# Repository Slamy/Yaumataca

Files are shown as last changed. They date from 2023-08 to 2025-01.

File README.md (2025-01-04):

# Yet another USB mouse and joystick to Amiga, Atari ST &amp; C64 Adapter

Or in short Yaumataca. This device allows to use modern USB input devices
on 80s style home computer controller ports. Being mechanical in nature, old gamepads and mouses
degrade over time and replacements using modern variants might be required.

This solution makes use of the Raspberry Pi Pico board (RP2040) which offers a dedicated USB host controller
and can be bought at a rather low price (5-8€ per unit).
Cheap NPN transistors are used for level shifting as the RP2040 is not 5V tolerant.

## How to use

The Yaumataca acts as both Joystick and Mouse. Plug both output ports into both controller ports of the target machine.
Plug a USB OTG Hub into the Micro-USB port of the Pico board. Insert USB gamepad and USB mouse.

As multiple modes are supported, the [user manual](doc/user_manual.md) provides more detail.

## Features
* Cheap to build
* Uses "off the shelf" hardware
* Multiple USB devices on 2 Atari type controller ports using a single unit
* Primary joystick on left port
* Primary mouse on right port
* Amiga mouse with wheel using [WheelBusMouse](http://aminet.net/package/util/mouse/WheelBusMouse) driver
* Commodore 1351 in proportional mode
* Atari ST mouse
* Automatic switch between mouses and joysticks
* Swap of controller ports (useful for C64 games)
* Supports 2 mouses and 2 joysticks (useful for Lemmings and Marble Madness)
* Supports secondary fire button (Amiga and C64 style)
* Auto fire
* Configured mouse type is saved in flash

## Restrictions
* Only dedicated Joysticks are supported.
	* PS3 DualShock
	* PS4 DualShock
	* Nintendo Switch Pro Controller
	* Xbox 360 Wireless Receiver (1 or 2 controllers with one receiver)
	* Xbox One Controller
	* Xbox Series S/X Controller
	* Mega World International - USB Game Controllers (07b5:0314)
	* DragonInc Hizue Gamepad (0079:0011)

## TODO
* Amiga Mode: Add support for newmouse or Micromys protocol
	* Avoids necessity for manipulation of the unrelated joystick port
* Add 3. Fire button for more gamepads
* HID Descriptor Parsing (generic USB joystick support, eventually)
* Bluetooth (eventually)
* Explain C1351 calibration using C64 tool

## How to construct

The project is constructable via perfboard or PCB.

[Manual for construction on a perfboard](doc/construction_perfboard.md)

For the PCB, please use the [KiCad files](schematic/yaumataca/).
If you order your parts from [Reichelt](https//reichelt.de), you may use the
attached [ordering lists](doc/reichelt.csv) which can be imported on the website.

In case the PCB is chosen, there is also a [3D model of a case](housing/) available, which can be used for 3D printing.

To operate the unit, one OTG Hub is recommended which provides multiple USB A ports attached to a USB micro port.
If only one USB device is to be attached, a simple USB micro to USB A adapter will also work, but I suggest to go for the Hub.

### Example hardware design

Here an example of the PCB inside the case.
Photo of Yaumataca in 3d printed case

Here the PCB side by side with the prototype.
Photo of Yaumataca build from PCB and perfboard

## How to build the firmware

Ensure that the submodules are also cloned.

	git submodule update --init --recursive
	mkdir build
	cd build
	cmake ..
	make

Alternatively there is also a small script which builds and packages the software as a zip file for upload.

	./scripts/build_release.sh

## How to flash

### Integrated USB bootloader

The RP2040 can be flashed using SWD or using the integrated USB bootloader.
As not everyone might have a debugger lying around, flash the Pico as so:

* Don't have the Pico board powered and connected.
* Press and hold the BOOTSEL button
* Connect the Pico to your PC while holding the button
* The Pico should be detected as mass storage device
* Copy `yaumataca.uf2` from the `build` folder to the device
* The LED of the Pico should start blinking

The Yaumataca is now ready for operation

### With SWD

This assumes that you are using a CMSIS-DAP compatible programmer. It is suggested to use a second Pico board as one.
This is possible using [the Picoprobe firmware](https://github.com/raspberrypi/picoprobe/releases).
Keep in mind that an st-link cannot be used with the RP2040, even so both speak SWD.

	openocd -f interface/cmsis-dap.cfg -f target/rp2040.cfg -c "adapter speed 20000; program build/yaumataca.elf verify reset exit"

Connect the picoprobe like so, to flash and debug the Yaumataca in standalone operation:

Example picture of an attached picoprobe to the Yaumataca

Keep in mind to only connect 5V (purple wire) when operating the Yaumataca without any home computer attached!
The 5V power supply is usually provided by the controller port and not from the PC!
It must not be delivered by both the developer PC and the homecomputer at the same time!

## Recommended IDE

Please use vscode and open the root folder with it.
This gives access to the already existing debugging targets.

## System architecture

uml diagram

## Doxygen and Unittests

It is my goal to have everything properly documented and tested

	scripts/check_doxygen.sh
	scripts/unittest.sh

## FAQ

### My gamepad is not supported. What can I do?

It depends. Some USB Gamepads are not following the HID standard, which is a huge
issue. The PS4 Controller is one rare exception which just works.
Bad examples are the Xbox One Controller and the Nintendo Switch Pro Controller.

Both require some sort of handshaking to activate the data transfer.

If you are lucky, you have a USB input device which just follows the HID standard.

[Please follow this guide to add additional gamepads](doc/adding_gamepads.md)

### I can see PRINTF all over the place. Where is the output going to?

This project makes use of "Segger RTT" which stores printed characters
inside a small buffer which can be displayed over SWD.
It has advantages compared to the UART as no additional GPIOs
have to be reserved for this.

I don't recommend to use rtthost as it is slow. Please use VSCode instead.

	rtthost -c rp2040

There is also pyocd available, which is faster:

	pyocd rtt --target rp2040

### SWD is failing with "Info : DAP init failed"

You have accidentally downloaded `debugprobe` and not `picoprobe`.
This project uses the CMSIS-DAP variant of the picoprobe!
One working version is [this one](https://github.com/raspberrypi/debugprobe/releases/tag/picoprobe-cmsis-v1.1).

### I can't use the C1351 mouse on "Final Cartridge III"

The design of the Yaumataca circuit might not be optimal, as it causes issues with the
way the FC3 software is using the SID muxes in desktop mode. For some reason, both Controller Ports
are muxed at the same time to the SIDs POT lines, so it can accept a mouse at either of the ports
without additional configuration. This however means that no two mice are allowed to be connected
at the same time.

The Yaumataca design is not aware of this and uses a 10k pullup on POT X and POT Y to charge the measurement capacitor.
This alone is not an issue. However, with the addition of the secondary fire buttons on the C64,
this indeed causes issues as the high state is the pressed state while the grounded state
is not pressed. This is opposite to how the Amiga handles its buttons.

If this issue occurs, just disconnect one of the controller ports.

### Why is this not written in Rust?

Because USB Host Support for the RP2040 is not yet awesome

### Isn't this yet another USB mouse and joystick to Amiga, Atari ST & C64 adapter

Exactly

### Funny anecdote

The popularity of this project was increased dramatically just becausean Atari ST
user was missing a mouse on a Commodore 64 party.
This happened on the DoReCo (Dortmund Retro Computer) Party 2024 in Anröche, Germany.

## Sources of Inspiration

My old project this here needs to surpass:<br>
http://slamyslab.blogspot.com/2013/02/pcbs-for-usb-datasette-and.html

Infos about Mouse Wheels on the Amiga:<br>
http://bax.comlab.uni-rostock.de/en/hardware/amiga-usb-mouse/

For the pinout:<br>
https://www.c64-wiki.de/wiki/Maus

Information about the Commodore 1351:<br>
http://sensi.org/~svo/%5Bm%5Douse/

Micromys C64 and Amiga Mouse Protocol:<br>
https://wiki.icomp.de/wiki/Micromys_Protocol

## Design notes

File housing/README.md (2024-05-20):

# 3D printed case

## Version 1

A single M2 screw is used to keep everything together. Button is reachable via rather big hole.
SWD port is usable even if PCB is in case.

Problems:

* Thick fingers are unable to reach the button. This is only a small issue however as the button is used rarely.
* Screw at the bottom is sticking out if head is not very flat.
* Structural integrity not perfect.

Photo of Yaumataca in 3d printed case

## Version 2

Based on Version 1 but with changes:

* Big hole is replaced by smaller one and a small piece of plastic is used as a button.
* Screw is moved to another location
* Bottom wall is thicker so screw head is not sticking out.

Photo of both versions side by side

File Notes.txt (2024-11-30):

impact game pad VID = 07b5, PID = 0314
05 01 09 04 a1 01 09 01 a1 00 09 30 09 31 09 32 09 35 15 00 26 ff 00 35 00 46 ff 00 66 00 00 75 08
95 04 81 02 c0 09 39 15 01 25 08 35 00 46 3b 01 65 14 75 04 95 01 81 02 05 09 19 01 29 0c 15 00 25
01 75 01 95 0c 55 00 65 00 81 02 05 08 09 43 15 00 26 ff 00 35 00 46 ff 00 75 08 95 04 91 82 55 00 65 00 55 00 65 00 55 00 c0 

0x05, 0x01,        // Usage Page (Generic Desktop Ctrls)
0x09, 0x04,        // Usage (Joystick)
0xA1, 0x01,        // Collection (Application)
0x09, 0x01,        //   Usage (Pointer)
0xA1, 0x00,        //   Collection (Physical)
0x09, 0x30,        //     Usage (X)
0x09, 0x31,        //     Usage (Y)
0x09, 0x32,        //     Usage (Z)
0x09, 0x35,        //     Usage (Rz)
0x15, 0x00,        //     Logical Minimum (0)
0x26, 0xFF, 0x00,  //     Logical Maximum (255)
0x35, 0x00,        //     Physical Minimum (0)
0x46, 0xFF, 0x00,  //     Physical Maximum (255)
0x66, 0x00, 0x00,  //     Unit (None)
0x75, 0x08,        //     Report Size (8)
0x95, 0x04,        //     Report Count (4)
0x81, 0x02,        //     Input (Data,Var,Abs,No Wrap,Linear,Preferred State,No Null Position)
0xC0,              //   End Collection
0x09, 0x39,        //   Usage (Hat switch)
0x15, 0x01,        //   Logical Minimum (1)
0x25, 0x08,        //   Logical Maximum (8)
0x35, 0x00,        //   Physical Minimum (0)
0x46, 0x3B, 0x01,  //   Physical Maximum (315)
0x65, 0x14,        //   Unit (System: English Rotation, Length: Centimeter)
0x75, 0x04,        //   Report Size (4)
0x95, 0x01,        //   Report Count (1)
0x81, 0x02,        //   Input (Data,Var,Abs,No Wrap,Linear,Preferred State,No Null Position)
0x05, 0x09,        //   Usage Page (Button)
0x19, 0x01,        //   Usage Minimum (0x01)
0x29, 0x0C,        //   Usage Maximum (0x0C)
0x15, 0x00,        //   Logical Minimum (0)
0x25, 0x01,        //   Logical Maximum (1)
0x75, 0x01,        //   Report Size (1)
0x95, 0x0C,        //   Report Count (12)
0x55, 0x00,        //   Unit Exponent (0)
0x65, 0x00,        //   Unit (None)
0x81, 0x02,        //   Input (Data,Var,Abs,No Wrap,Linear,Preferred State,No Null Position)
0x05, 0x08,        //   Usage Page (LEDs)
0x09, 0x43,        //   Usage (Slow Blink On Time)
0x15, 0x00,        //   Logical Minimum (0)
0x26, 0xFF, 0x00,  //   Logical Maximum (255)
0x35, 0x00,        //   Physical Minimum (0)
0x46, 0xFF, 0x00,  //   Physical Maximum (255)
0x75, 0x08,        //   Report Size (8)
0x95, 0x04,        //   Report Count (4)
0x91, 0x82,        //   Output (Data,Var,Abs,No Wrap,Linear,Preferred State,No Null Position,Volatile)
0x55, 0x00,        //   Unit Exponent (0)
0x65, 0x00,        //   Unit (None)
0x55, 0x00,        //   Unit Exponent (0)
0x65, 0x00,        //   Unit (None)
0x55, 0x00,        //   Unit Exponent (0)
0xC0,              // End Collection

// 108 bytes

Report Example:
80 80 80 80 00 00
--                  Left Stick X
   --               Left Stick Y
      --            Right Stick Y
         --         Right Stick X
            -  --   Buttons
             -      Coolie Hat / D-Pad

Logitech USB Mouse
VID = 046d, PID = c03e
HID Interface Protocol = Mouse

05 01 09 02 a1 01 09 01 a1 00 05 09 19 01 29 03 15 00 25 01 95 03 75 01 81 02
95 05 81 03 05 01 09 30 09 31 09 38 15 81 25 7f 75 08 95 03 81 06 c0 c0 

0x05, 0x01,        // Usage Page (Generic Desktop Ctrls)
0x09, 0x02,        // Usage (Mouse)
0xA1, 0x01,        // Collection (Application)
0x09, 0x01,        //   Usage (Pointer)
0xA1, 0x00,        //   Collection (Physical)
0x05, 0x09,        //     Usage Page (Button)
0x19, 0x01,        //     Usage Minimum (0x01)
0x29, 0x03,        //     Usage Maximum (0x03)
0x15, 0x00,        //     Logical Minimum (0)
0x25, 0x01,        //     Logical Maximum (1)
0x95, 0x03,        //     Report Count (3)
0x75, 0x01,        //     Report Size (1)
0x81, 0x02,        //     Input (Data,Var,Abs,No Wrap,Linear,Preferred State,No Null Position)
0x95, 0x05,        //     Report Count (5)
0x81, 0x03,        //     Input (Const,Var,Abs,No Wrap,Linear,Preferred State,No Null Position)
0x05, 0x01,        //     Usage Page (Generic Desktop Ctrls)
0x09, 0x30,        //     Usage (X)
0x09, 0x31,        //     Usage (Y)
0x09, 0x38,        //     Usage (Wheel)
0x15, 0x81,        //     Logical Minimum (-127)
0x25, 0x7F,        //     Logical Maximum (127)
0x75, 0x08,        //     Report Size (8)
0x95, 0x03,        //     Report Count (3)
0x81, 0x06,        //     Input (Data,Var,Rel,No Wrap,Linear,Preferred State,No Null Position)
0xC0,              //   End Collection
0xC0,              // End Collection

// 50 bytes

Report Example:

00 00 00 00
--            Buttons on lower 3 Bits
   --         Relative X
      --      Relative Y
         --   Relative Wheel

Ziel: USB HID -> Amiga Maus/Joystick + C64 Joystick
RP2040? Hat USB Host aber keine 5V toleranten IO

Pegelwandlung wie?
Bipolar? Kleine MOSFETs? Müssen ja nicht viel treiben...
Pegelwandler ICs?
74HCT244N ?
Sollte auch Open Drain unterstützen, weil das eher einem Joystick entspricht. Kein Push/Pull
74HCT125 wäre mit Output Enable für jeden Pin. Ist aber wahrscheinlich größer als 12 kleine MOSFETs

STM32F4? Hat USB Host und 5V tolerante I/O. Gibt aber kaum kleine süße Boards.
Oder?

https://www.az-delivery.de/products/stm32f401-development-board-v-3-0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

Generell 2 Joysticks / Mäuse.
USB Hub notwendig.
USB C / USB Micro auf USB Hub auf mehrere USB A

https://www.amazon.de/gp/product/B0BLSL7L3Y/ref=ox_sc_act_image_1?smid=A2Y91ZFTIMU0N5&psc=1

https://www.amazon.de/Zerone-Adapterkabel-Android-Tablet-Smartphone-default/dp/B07P8KW6SX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

https://ww1.microchip.com/downloads/en/DeviceDoc/chapter%208.pdf

Use Case Analysis:

On the back of the Amiga, the left port is the joystick port, the right is the mouse port.
For two mouses the joystick port is used as second mouse.
For two joysticks the mouse port is used as second joystick.

First joystick is connected to the joystick port on detection.
First mouse is connected to the mouse port on detection.

Joysticks have a secondary fire button next to the primary.
A button on the joystick is an auto fire.
A button on the joystick can be used to swap ports. This is important for the C64 as games didn't agree on that one.
It shall never be required to swap controller ports in hardware.

The Atari ST mouse is similar to the Amiga mouse. Changing Configuration somehow must be possible. How?
User Button on the Pico? It isn't used yet.
Press User button and Left Mouse button to Switch to Amiga.
Press User button and Right Mouse button to Switch to Atari ST.
Press User button and Middle Mouse button to Switch to C1351.

If two joysticks are connected, the second joystick shares signals with the primary mouse.
If the primary mouse is moved significantly or a button is clicked it is activated.
If a button on the joystick is pressed it is activated instead.

VICE C64 Emulator
1351 von 64 bis 191.
191 bricht um zu 64.

Comprehensive list of games and apps that used 1351 mouse
https://www.lemon64.com/forum/viewtopic.php?t=61515

Source of Pico Pinout:
https://www.raspberrypi.com/documentation/microcontrollers/images/pico-pinout.svg

https://docs.kernel.org/hid/hidintro.html
https://eleccelerator.com/usbdescreqparser/

## rapoo mouse

05 01 09 02 a1 01 85 01 09 01 a1 00 05 09 19 01 29 03 15 00 25 01 75 01 95 05 81 02 75 03 95 01 81 01 05 01 09 30 09 31
16 01 80 26 ff 7f 75 10 95 02 81 06 09 38 15 81 25 7f 75 08 95 01 81 06 c0 c0 05 0c 09 01 a1 01 85 02 75 10 95 01 15 01
26 8c 02 19 01 2a 8c 02 81 00 c0 05 01 09 80 a1 01 85 03 09 82 09 81 09 83 15 00 25 01 19 01 29 03 75 01 95 03 81 02 95
05 81 01 c0 05 01 09 00 a1 01 85 05 06 00 ff 09 01 15 81 25 7f 75 08 95 07 b1 02 c0 06 00 ff 09 0e a1 01 85 ba 95 1f 75
08 26 ff 00 15 00 09 01 91 02 85 ba 95 1f 75 08 26 ff 00 15 00 09 01 81 02 c0

0x05, 0x01,        // Usage Page (Generic Desktop Ctrls)
0x09, 0x02,        // Usage (Mouse)
0xA1, 0x01,        // Collection (Application)
0x85, 0x01,        //   Report ID (1)
0x09, 0x01,        //   Usage (Pointer)
0xA1, 0x00,        //   Collection (Physical)
0x05, 0x09,        //     Usage Page (Button)
0x19, 0x01,        //     Usage Minimum (0x01)
0x29, 0x03,        //     Usage Maximum (0x03)
0x15, 0x00,        //     Logical Minimum (0)
0x25, 0x01,        //     Logical Maximum (1)
0x75, 0x01,        //     Report Size (1)
0x95, 0x05,        //     Report Count (5)
0x81, 0x02,        //     Input (Data,Var,Abs,No Wrap,Linear,Preferred State,No Null Position)
0x75, 0x03,        //     Report Size (3)
0x95, 0x01,        //     Report Count (1)
0x81, 0x01,        //     Input (Const,Array,Abs,No Wrap,Linear,Preferred State,No Null Position)
0x05, 0x01,        //     Usage Page (Generic Desktop Ctrls)
0x09, 0x30,        //     Usage (X)
0x09, 0x31,        //     Usage (Y)
0x16, 0x01, 0x80,  //     Logical Minimum (-32767)
0x26, 0xFF, 0x7F,  //     Logical Maximum (32767)
0x75, 0x10,        //     Report Size (16)
0x95, 0x02,        //     Report Count (2)
0x81, 0x06,        //     Input (Data,Var,Rel,No Wrap,Linear,Preferred State,No Null Position)
0x09, 0x38,        //     Usage (Wheel)
0x15, 0x81,        //     Logical Minimum (-127)
0x25, 0x7F,        //     Logical Maximum (127)
0x75, 0x08,        //     Report Size (8)
0x95, 0x01,        //     Report Count (1)
0x81, 0x06,        //     Input (Data,Var,Rel,No Wrap,Linear,Preferred State,No Null Position)
0xC0,              //   End Collection
0xC0,              // End Collection
0x05, 0x0C,        // Usage Page (Consumer)
0x09, 0x01,        // Usage (Consumer Control)
0xA1, 0x01,        // Collection (Application)
0x85, 0x02,        //   Report ID (2)
0x75, 0x10,        //   Report Size (16)
0x95, 0x01,        //   Report Count (1)
0x15, 0x01,        //   Logical Minimum (1)
0x26, 0x8C, 0x02,  //   Logical Maximum (652)
0x19, 0x01,        //   Usage Minimum (Consumer Control)
0x2A, 0x8C, 0x02,  //   Usage Maximum (AC Send)
0x81, 0x00,        //   Input (Data,Array,Abs,No Wrap,Linear,Preferred State,No Null Position)
0xC0,              // End Collection
0x05, 0x01,        // Usage Page (Generic Desktop Ctrls)
0x09, 0x80,        // Usage (Sys Control)
0xA1, 0x01,        // Collection (Application)
0x85, 0x03,        //   Report ID (3)
0x09, 0x82,        //   Usage (Sys Sleep)
0x09, 0x81,        //   Usage (Sys Power Down)
0x09, 0x83,        //   Usage (Sys Wake Up)
0x15, 0x00,        //   Logical Minimum (0)
0x25, 0x01,        //   Logical Maximum (1)
0x19, 0x01,        //   Usage Minimum (Pointer)
0x29, 0x03,        //   Usage Maximum (0x03)
0x75, 0x01,        //   Report Size (1)
0x95, 0x03,        //   Report Count (3)
0x81, 0x02,        //   Input (Data,Var,Abs,No Wrap,Linear,Preferred State,No Null Position)
0x95, 0x05,        //   Report Count (5)
0x81, 0x01,        //   Input (Const,Array,Abs,No Wrap,Linear,Preferred State,No Null Position)
0xC0,              // End Collection
0x05, 0x01,        // Usage Page (Generic Desktop Ctrls)
0x09, 0x00,        // Usage (Undefined)
0xA1, 0x01,        // Collection (Application)
0x85, 0x05,        //   Report ID (5)
0x06, 0x00, 0xFF,  //   Usage Page (Vendor Defined 0xFF00)
0x09, 0x01,        //   Usage (0x01)
0x15, 0x81,        //   Logical Minimum (-127)
0x25, 0x7F,        //   Logical Maximum (127)
0x75, 0x08,        //   Report Size (8)
0x95, 0x07,        //   Report Count (7)
0xB1, 0x02,        //   Feature (Data,Var,Abs,No Wrap,Linear,Preferred State,No Null Position,Non-volatile)
0xC0,              // End Collection
0x06, 0x00, 0xFF,  // Usage Page (Vendor Defined 0xFF00)
0x09, 0x0E,        // Usage (0x0E)
0xA1, 0x01,        // Collection (Application)
0x85, 0xBA,        //   Report ID (-70)
0x95, 0x1F,        //   Report Count (31)
0x75, 0x08,        //   Report Size (8)
0x26, 0xFF, 0x00,  //   Logical Maximum (255)
0x15, 0x00,        //   Logical Minimum (0)
0x09, 0x01,        //   Usage (0x01)
0x91, 0x02,        //   Output (Data,Var,Abs,No Wrap,Linear,Preferred State,No Null Position,Non-volatile)
0x85, 0xBA,        //   Report ID (-70)
0x95, 0x1F,        //   Report Count (31)
0x75, 0x08,        //   Report Size (8)
0x26, 0xFF, 0x00,  //   Logical Maximum (255)
0x15, 0x00,        //   Logical Minimum (0)
0x09, 0x01,        //   Usage (0x01)
0x81, 0x02,        //   Input (Data,Var,Abs,No Wrap,Linear,Preferred State,No Null Position)
0xC0,              // End Collection

// 186 bytes

## Logitech M100

05 01 09 02 a1 01 09 01 a1 00 05 09 19 01 29 03 15 00 25 01 95 08 75 01 81 02 05 01 09 30 09 31 09 38 15 81 25 7f 75 08
95 03 81 06 c0 c0

0x05, 0x01,        // Usage Page (Generic Desktop Ctrls)
0x09, 0x02,        // Usage (Mouse)
0xA1, 0x01,        // Collection (Application)
0x09, 0x01,        //   Usage (Pointer)
0xA1, 0x00,        //   Collection (Physical)
0x05, 0x09,        //     Usage Page (Button)
0x19, 0x01,        //     Usage Minimum (0x01)
0x29, 0x03,        //     Usage Maximum (0x03)
0x15, 0x00,        //     Logical Minimum (0)
0x25, 0x01,        //     Logical Maximum (1)
0x95, 0x08,        //     Report Count (8)
0x75, 0x01,        //     Report Size (1)
0x81, 0x02,        //     Input (Data,Var,Abs,No Wrap,Linear,Preferred State,No Null Position)
0x05, 0x01,        //     Usage Page (Generic Desktop Ctrls)
0x09, 0x30,        //     Usage (X)
0x09, 0x31,        //     Usage (Y)
0x09, 0x38,        //     Usage (Wheel)
0x15, 0x81,        //     Logical Minimum (-127)
0x25, 0x7F,        //     Logical Maximum (127)
0x75, 0x08,        //     Report Size (8)
0x95, 0x03,        //     Report Count (3)
0x81, 0x06,        //     Input (Data,Var,Rel,No Wrap,Linear,Preferred State,No Null Position)
0xC0,              //   End Collection
0xC0,              // End Collection

// 46 bytes

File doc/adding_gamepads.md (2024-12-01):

# Adding a new HID gamepad

## Prerequisites

If you don't feel confident with programming in C, stop reading now to avoid unnecessary pain.

You need some basic knowledge about C++, CMake and cross compilation.
It would also be a good thing to have some knowledge about "Segger RTT" as this is the primary method for debugging output.

You need a SWD debugger which is compatible with the RP Pico. If unsure, get another
RP Pico and use [this firmware](https://github.com/raspberrypi/picoprobe/) to build a very cheap CMSIS-DAP debugger.
Ensure it is the picoprobe with CMSIS support.

I recommend VS Code as IDE for development and debugging.

## Enabling Debugging messages

Edit the CMake Cache and enable `CONFIG_DEBUG_PRINT` to activate RTT output.
If you run the application inside VS Code, it will activate the RTT console and you can see your output.

If you don't want to use the VSCode internal RTT Console, you can use rtthost too:

    rtthost -c rp2040

Or pyocd:

	pyocd rtt --target rp2040

A possible output might be this:

    Yaumataca says hello!
    JoystickMouseSwitcher +
    JoystickMouseSwitcher +
    Found configuration byte 0x2 at offset 0x19
    Pipeline +
    GPIOs set for joystick mode on left port
    GPIOs set for joystick mode on right port
    PortSwitcher + 20005040
    PortSwitcher + 20005070
    MouseModeSwitcher +
    MouseModeSwitcher +
    GamePadFeatures +
    GamePadFeatures +
    Set mouse mode 2
    C1351Converter +
    Set mouse mode 2
    C1351Converter +
    C1351 calibration previously stored. Use it!
    C1351 calibration -1546 -1301 -1406 -1164
    C1351 calibration -1555 -1316 -1412 -1177
    R 0000 011
    L 0000 011

## Checking for standard HID reports

You need to know the VID and PID of the pad to continue.
Also, we would like to know whether the gamepad is transmitting some report data.
With the debugging output at hand, connect a gamepad:

    HID device address = 1, instance = 0 is mounted
    VID = 046d, PID = c20c
    HID has 1 reports 0 4 1
    Device attached, address = 1
    HID device address = 1 is mounted
    VID = 046d, PID = c20c

This is good! We now have knowledge about the VID and the PID.
Press some buttons on your gamepad now.

    Report: 00 80 80
    Report: 04 80 80
    Report: 00 80 80
    Report: 04 80 80
    Report: 00 80 80
    Report: 01 80 80
    Report: 03 80 80

This is a good thing! This is an indication that your gamepad is providing reports of some sort without requesting
it to do so via non-standard methods.
The output you see is a hex representation of the HID report. Bits are flipping when you press buttons.

## Starting with a template

Make a duplicate of [this rather simple and usable handler](../src/handlers/hid_impact.cpp).

`hid_impact.cpp` is for a rather old gamepad, I had around when this project was started.
It might make sense to use this as inspiration.

Rename the class `ImpactHidHandler` to something which makes sense for your device.
This gamepad has "impact" written on it, so I thought it made sense to call it that.

Look for the `HidHandlerBuilder` at the bottom of the file and replace the VID and PID.

Don't forget to add this file to the [CMakeLists.txt](../CMakeLists.txt) next to the other handlers.

The class has a method which needs to be implemented. It is called on every report, the input delivers to us:

```c++
void process_report(std::span<const uint8_t> d) {
}
```

It makes sense to start with some debugging messages to analyze the reports for their structure.
Do you have activated the PRINTF inside your handler? Something like this?

    PRINTF("XYZ: ");
    for (uint8_t i : d) {
        PRINTF(" %02x", i);
    }
    PRINTF("\n");

If yes, press some buttons! What does happen?
Something like this?

    XYZ:  80 80 80 80 05 00
    XYZ:  80 80 80 80 06 00
    XYZ:  80 80 80 80 07 00
    XYZ:  80 80 80 80 00 00
    XYZ:  80 80 80 80 03 00

## Mapping the buttons of the gamepad

What to do with that data? Let's use `hid_impact.cpp` as an example.
Every line in the `Report` structure marks a set of bits, giving a name to them which we can later use for parsing.

```c++
struct __attribute__((packed)) Report {
    // Byte 0 to 3
    uint8_t joy_left_x;
    uint8_t joy_left_y;
    uint8_t joy_right_y;
    uint8_t joy_right_x;

    // Byte 4
    uint8_t coolie_hat : 4;
    uint8_t button_left : 1;
    uint8_t button_top : 1;
    uint8_t button_bottom : 1;
    uint8_t button_right : 1;

    // Byte 5
    uint8_t trigger_l1 : 1;
    uint8_t trigger_l2 : 1;
    uint8_t trigger_r1 : 1;
    uint8_t trigger_r2 : 1;
    uint8_t button_select : 1;
    uint8_t button_start : 1;
    uint8_t stick_click_left : 1;
    uint8_t stick_click_right : 1;
};
```

With this controller, the first 4 bytes are an unsigned representation of both analog sticks with 0x80 being the center state.

By moving the left stick, the software will print this:

    Impact: 0 0000 80 81 80 80 00 00
    Impact: 0 0000 80 81 80 80 00 00
    Impact: 0 0000 74 ff 80 80 00 00
    Impact: 0 0000 6e af 80 80 00 00
    Impact: 0 0000 80 80 80 80 00 00

By clicking the left button on the front 4 buttons (would be square on PS1 controller) I get this

    Impact: 0 1000 80 80 80 80 10 00
    Impact: 0 0000 80 80 80 80 00 00

Now - by observing the change - I know the bit position of this specific button!

Keep in mind that some gamepads don't implement the D-Pad as 4 buttons but instead as a Coolie-Hat with one value for each direction.
`hid_impact.cpp` is one example for such a case.

There are also gamepads around which are implementing the D-Pad as virtual analog axes.
The DragonRise Controller `(0079:0011)` is one of those examples.

You now need to fill out
```c++
struct __attribute__((packed)) Report {
}
```

Get yourself some inspiration from the other handlers. Get creative!
The `GamepadReport` must be filled with button states:

```c++
bool fire : 1;          ///< Fire1
bool sec_fire : 1;      ///< Fire2
bool third_fire : 1;    ///< Fire3
bool auto_fire : 1;     ///< Turbo Fire1
bool up : 1;            ///< D-Pad Up
bool down : 1;          ///< D-Pad Down
bool left : 1;          ///< D-Pad Left
bool right : 1;         ///< D-Pad Right
bool joystick_swap : 1; ///< If pressed for a second, both controller ports swap
```

Please use [hid_impact](../src/handlers/hid_impact.cpp) and [hid_ps4.cpp](../src/handlers/hid_ps4.cpp)
as examples for input devices with a simple handling.

For the impact gamepad, the layout is dictated by these lines:
```c++
GamepadReport aj;

aj.update_from_coolie_hat(dat->coolie_hat); // Coolie Hat D-Pad

aj.fire = dat->button_left || dat->button_right;
aj.sec_fire = dat->button_bottom;
aj.auto_fire = dat->button_top;

aj.joystick_swap = dat->button_select;
```

## Did I do it right?

Without connecting the Yaumataca to your homecomputer, you can already check if things are implemented correctly.

The current Controller state is printed to the output as well.

    XYZ:  80 80 80 80 05 00
    L 0010 011
    XYZ:  80 80 80 80 00 00
    L 0000 011

`L` refers to the left controller, the primary joystick.
The first 4 digits are the directional states of the controller port to your homecomputer.
The last 3 digits are the fire buttons.
By pressing buttons you can see whether these match your expectations.

## What can I do if a button press doesn't produce a HID report?

Some controllers require a non-standard protocol. You may need to investigate now, why this happens.

The project https://github.com/felis/USB_Host_Shield_2.0 might provide you with some insight as this library is rather feature-complete.

## What to do if everything works?

Please make a Pull Request on Github. Other gamers might also like your contribution to this project.

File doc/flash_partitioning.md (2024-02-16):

# User flash

| Name | Start | Size |
| --- | ---: | ---- |
| Application | 0x0 | |
| Mouse Mode FEE | 0x40000 | 4k |
| C1351 Calibration | 0x41000 | 4k |

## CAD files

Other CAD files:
housing/housing_v2-Main.stl
housing/housing_v2-Button.stl
housing/housing_v2.FCStd
housing/housing_v2-Cap.stl
housing/housing_v1-main.stl
housing/housing_v1.FCStd
housing/housing_v1-cap.stl

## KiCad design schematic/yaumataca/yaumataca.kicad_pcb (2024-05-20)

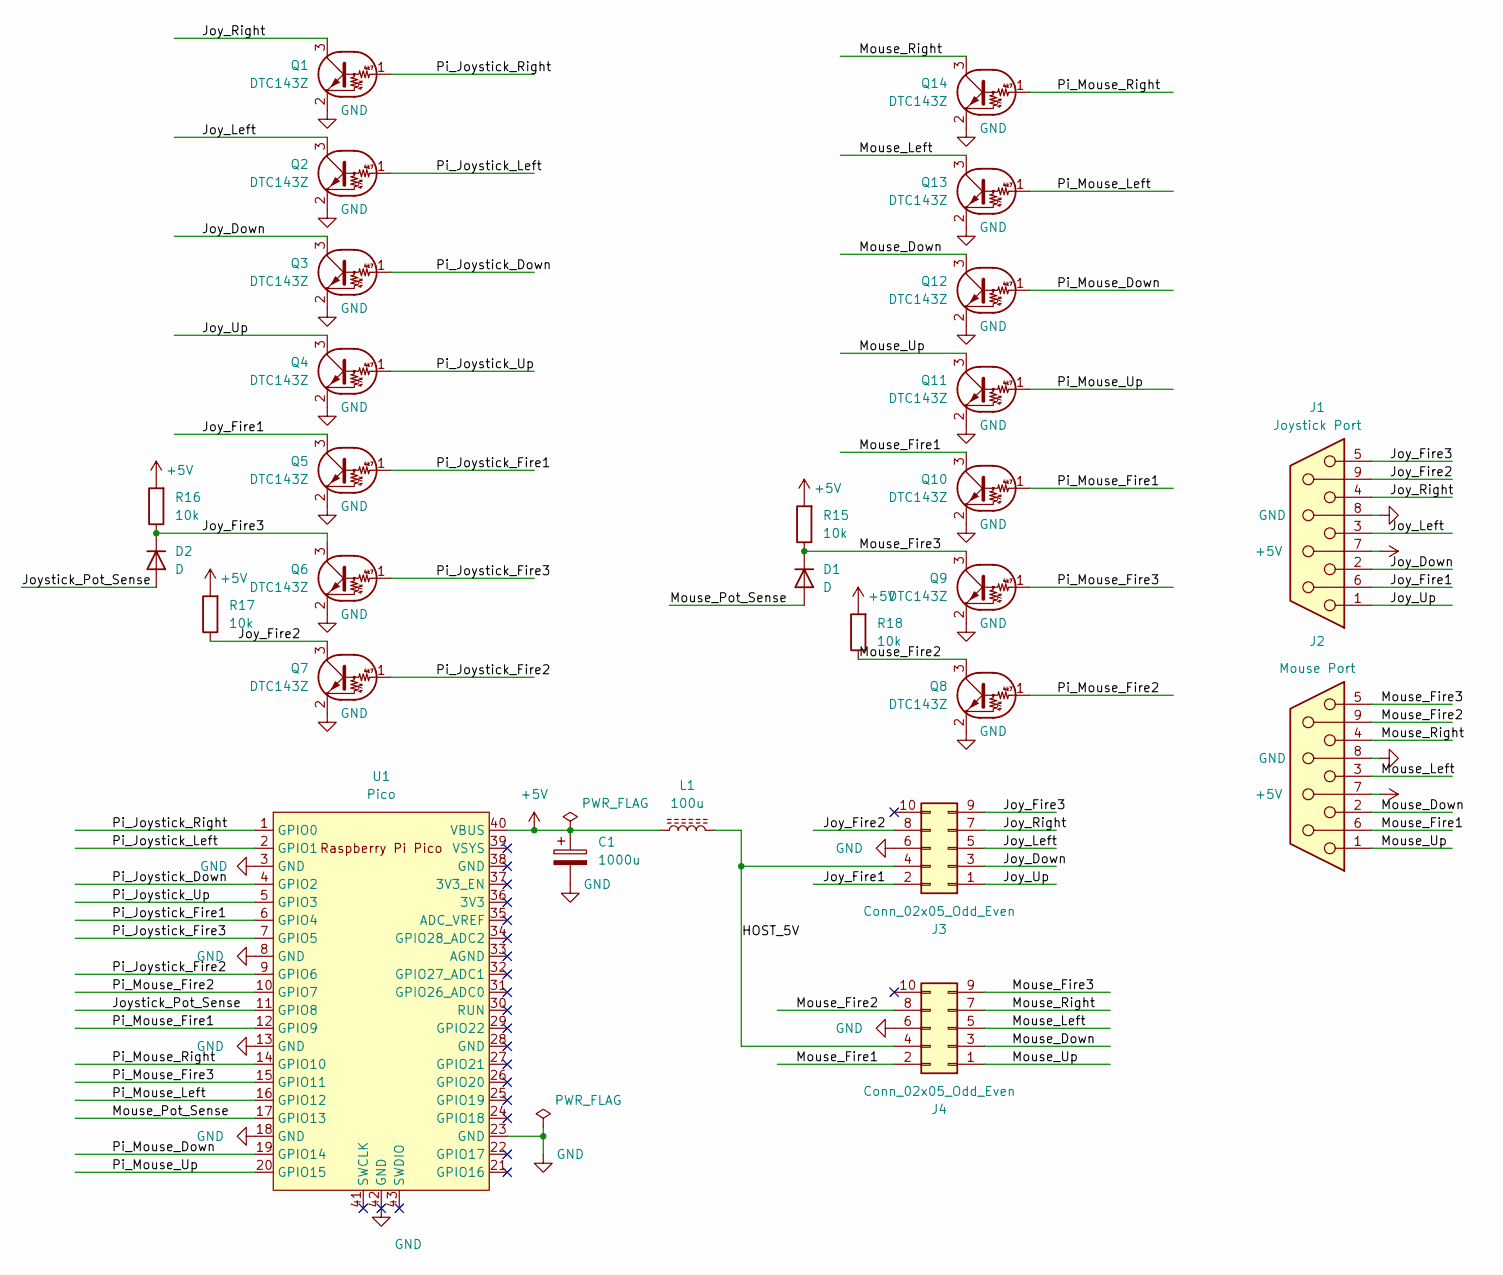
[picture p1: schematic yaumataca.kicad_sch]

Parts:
C1: 1000u; CP_Radial_D10.0mm_P5.00mm
D1, D2: D; D_SOD-123
J1: Joystick Port; DSUB-9_Female_Horizontal_P2.77x2.84mm_EdgePinOffset4.94mm_H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
J2: Mouse Port; DSUB-9_Female_Horizontal_P2.77x2.84mm_EdgePinOffset4.94mm_H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
J3, J4: Conn_02x05_Odd_Even; IDC-Header_2x05_P2.54mm_Vertical
L1: 100u; L_Axial_L5.3mm_D2.2mm_P7.62mm_Horizontal_Vishay_IM-1
Q1, Q2, Q3, Q4, Q5, Q6, Q7, Q8, Q9, Q10, Q11, Q12, Q13, Q14: DTC143Z; SOT-23_ohnesilk
R15, R16, R17, R18: 10k; R_0805_2012Metric_Pad1.20x1.40mm_HandSolder
U1: Pico; RPi_Pico_SMD_TH

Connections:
+5V: C1.1, J1.7, J2.7, L1.1, R15.2, R16.2, R17.2, R18.2, U1.40 (VBUS)
/HOST_5V: J3.4, J4.4, L1.2
/Joy_Down: J1.2, J3.3, Q3.3 (C)
/Joy_Fire1: J1.6, J3.2, Q5.3 (C)
/Joy_Fire2: J1.9, J3.8, Q7.3 (C), R17.1
/Joy_Fire3: D2.1 (K), J1.5, J3.9, Q6.3 (C), R16.1
/Joy_Left: J1.3, J3.5, Q2.3 (C)
/Joy_Right: J1.4, J3.7, Q1.3 (C)
/Joy_Up: J1.1, J3.1, Q4.3 (C)
/Joystick_Pot_Sense: D2.2 (A), U1.11 (GPIO8)
/Mouse_Down: J2.2, J4.3, Q12.3 (C)
/Mouse_Fire1: J2.6, J4.2, Q10.3 (C)
/Mouse_Fire2: J2.9, J4.8, Q8.3 (C), R18.1
/Mouse_Fire3: D1.1 (K), J2.5, J4.9, Q9.3 (C), R15.1
/Mouse_Left: J2.3, J4.5, Q13.3 (C)
/Mouse_Pot_Sense: D1.2 (A), U1.17 (GPIO13)
/Mouse_Right: J2.4, J4.7, Q14.3 (C)
/Mouse_Up: J2.1, J4.1, Q11.3 (C)
/Pi_Joystick_Down: Q3.1 (B), U1.4 (GPIO2)
/Pi_Joystick_Fire1: Q5.1 (B), U1.6 (GPIO4)
/Pi_Joystick_Fire2: Q7.1 (B), U1.9 (GPIO6)
/Pi_Joystick_Fire3: Q6.1 (B), U1.7 (GPIO5)
/Pi_Joystick_Left: Q2.1 (B), U1.2 (GPIO1)
/Pi_Joystick_Right: Q1.1 (B), U1.1 (GPIO0)
/Pi_Joystick_Up: Q4.1 (B), U1.5 (GPIO3)
/Pi_Mouse_Down: Q12.1 (B), U1.19 (GPIO14)
/Pi_Mouse_Fire1: Q10.1 (B), U1.12 (GPIO9)
/Pi_Mouse_Fire2: Q8.1 (B), U1.10 (GPIO7)
/Pi_Mouse_Fire3: Q9.1 (B), U1.15 (GPIO11)
/Pi_Mouse_Left: Q13.1 (B), U1.16 (GPIO12)
/Pi_Mouse_Right: Q14.1 (B), U1.14 (GPIO10)
/Pi_Mouse_Up: Q11.1 (B), U1.20 (GPIO15)
GND: C1.2, J1.8, J2.8, J3.6, J4.6, Q1.2 (E), Q2.2 (E), Q3.2 (E), Q4.2 (E), Q5.2 (E), Q6.2 (E), Q7.2 (E), Q8.2 (E), Q9.2 (E), Q10.2 (E), Q11.2 (E), Q12.2 (E), Q13.2 (E), Q14.2 (E), U1.3 (GND), U1.8 (GND), U1.13 (GND), U1.18 (GND), U1.23 (GND), U1.42 (GND)

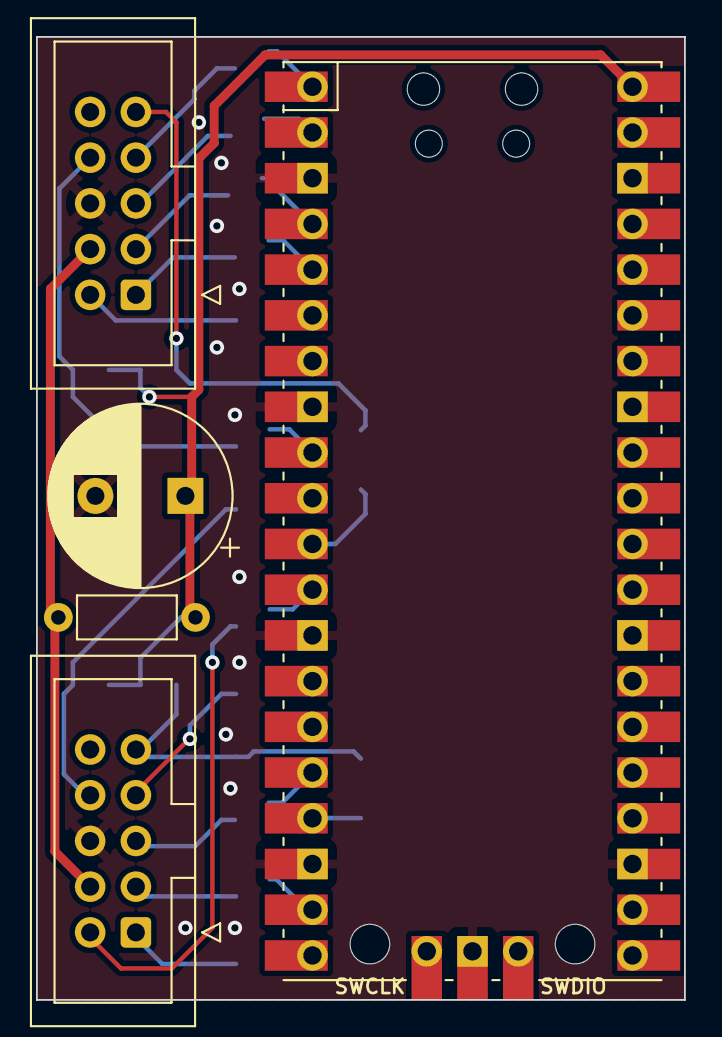
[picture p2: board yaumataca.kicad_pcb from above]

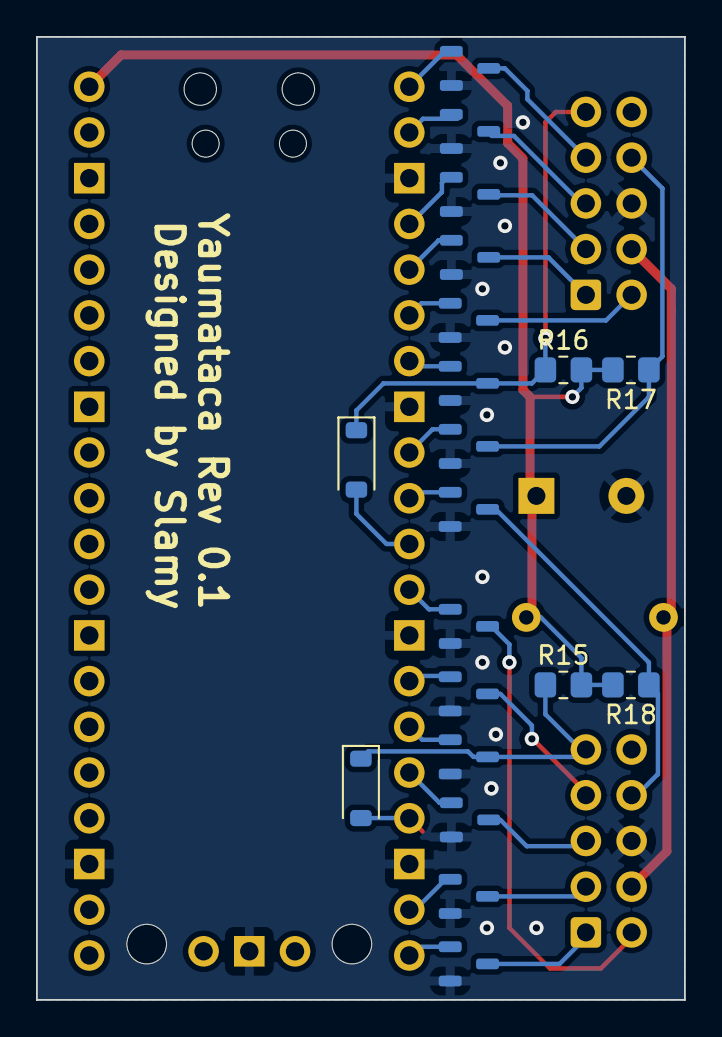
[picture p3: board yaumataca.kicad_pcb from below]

Board: 2 copper layers, 36.0 x 53.5 mm, 25 parts (20 on the bottom side), 33 nets.

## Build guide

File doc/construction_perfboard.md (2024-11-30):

# How to construct on a perfboard

Here an example, how it could be build using BC547 transistors and 10k resistors.

Photo of Yaumataca
Photo of Yaumataca from other angle

## Overview

Use the photos as guidance.

It is encouraged to use a 2x5 pinheader instead of soldering the female d-sub connector to the board. It has a smaller footprint and ensures that both connectors will find their counterpart on the home computer as the distance will differ between the systems.

Especially with the Atari ST, there is not much room under the keyboard.

Pinout

## Simplified schematic

Reduced to the essentials. The sense pins are only required for C1351 mode as the internal logic has to synchronize with the measurement cycle of the SID.

Simple schematic

## Schematic

The whole circuit

Schematic

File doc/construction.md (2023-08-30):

# How to construct

At the moment, no PCB design is available. However, a KiCad schematic exists and could be expanded to a PCB.
The protoype is based on a small perfboard as seen in the readme.

## Overview

It is encouraged to use a 2x5 pinheader instead of soldering the female d-sub connector to the board. It has a smaller footprint and ensures that both connectors will find their counterpart on the home computer as the distance will differ between the systems.

Especially with the Atari ST, there is not much room under the keyboard.

Pinout

## Simplified schematic

Reduced to the essentials...

Simple schematic

## Schematic

The whole circuit

Schematic

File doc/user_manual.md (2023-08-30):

# Yaumataca User Manual

The Yaumataca acts as both Joystick and Mouse. Plug both output ports into both controller ports of the target machine.
The device is intended for usage with the Commodore Amiga, C64 and Atari ST systems. Do not plug this device into an Amstrad CPC as the joystick ports work differently.

## Gamepad Layout

It is assumed that most gamepads nowadays have a layout similiar to a Super Nintendo Controller. From 1993 to 2023, this statement seems valid and unbroken. We use a PlayStation controller as reference here.

Button layout

## Startup behaviour

When the machine boots up, it will enumerate the attached USB devices.
Every found device will be acknowledged by a short flash of the user LED.

The first detected joystick will be attached to the left port.

The first detected mouse will be attached to the right port.

For the Amiga and the Atari ST this seems to be the best approach, as the controller ports have dedicated roles and most games will follow them.
For the C64 this is a different story as no norm exists on which controller port shall be used for which purpose.

## Automatic swapping of second joystick and mouse

With both the Amiga and the Atari ST a second joystick is attached to the mouse port and a second mouse has to be attached to the joystick port. This is cumbersome as constant replugging of devices is required.

The Yaumataca detects changes on the USB devices and automatically swaps between first mouse / second joystick and first joystick / second mouse.
This way you can have your primary joystick and primary mouse always attached to the system and just add additional devices.

## Swapping the controller ports

This is important for the C64.
To trigger the controller port swap via an attached gamepad, press and hold the SELECT button. The user LED of the Pico board will flash, indicating that the change was performed.
To trigger the swap via mouse, press and hold all 3 mouse buttons until the LED is flashing.

## Changing the type of emulated mouse

The device can act as an Amiga mouse, an Atari ST mouse and as a C1351 in proportional mode.
It should be noted that none of these systems are damaged by the wrong type of mouse. It just won't work.

To cycle through the types of mouses, press the user button of the Raspberry Pi Pico board. The user led will indicate all 3 variants via LED flashing patterns.

* 3x short -> Amiga
* short long short -> Atari ST
* 2x long -> C1351

The configuration is stored permanently and is not required to be performed everytime.

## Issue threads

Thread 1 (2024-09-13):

how to enable debug printf

andreacampanella, 2024-09-13:
I built one of this but something it's wrong and I would like to figure out how to get the debug output, I build with cmake -DCONFIG_DEBUG_PRINT=ON but the UART is shared with the cotroller port as soon as it gets initialised the debug print stops? can I disable the controller or just move the pins?

Slamy, 2024-09-14:
Feel free to create an issue after days instead of a week. Let's look.

I first try to answer the first question which I think you have deleted. I don't use an UART for printf debugging. Please never use an UART again for printf debugging. The RP2040 is capable of doing RTT. The vscode Projekt does it automatically. By enabling CONFIG_DEBUG_PRINT you enable the printf output over RTT. Please look into it, it is very useful as it doesn't take up any pins. But you need to have a debugger attached for it, which can just be another Rp Pico.

Next the problem itself. I think you have the Yaumataca in C1351 mode. You may need to press the button to cycle through the modes. What computer do you have? Amiga? Quadrature on mouse click sounds extremly like C1351.
Press once again for Amiga. Press again after that for Atari ST.
The sense pins are only for C1351 mode and can be left out for Amiga and Atari ST

Slamy, 2024-09-14:
You are the unlucky first person which has ever created an issue here. But with every issue I can sense the problems this project has and improve it.

andreacampanella, 2024-09-15:
Yes, I deleted the issue as I figured that one out, but I didn't had a second pico or a debugger, according to the printouts, it's running in Amiga mode, I should have 2 pairs of quandrature output, but on the scope I can only see one output per axis

Slamy, 2024-09-15:
Alright. You've found an issue. I've looked again at the svg files and it seems that after I've done the PCB, I forgot to update the first svg. The commits are squashed. I had an old version, where the old pinout is still used. At first there was no intent of making a PCB. This is where the first SVG was right. It was intended for manual wiring.
The kicad svg is the right one. Are you able to measure signals there? There should be quadrature there

Slamy, 2024-09-15:
If you see the prints, when moving the mouse there should be a display of the quadrature signals. I would expect that these are also present on the pins. There is not much between the outer pads and those prints.
I've also now created a branch called develop which has the svg updated. I hope I can somehow help you.

andreacampanella, 2024-09-15:
Here is a log of what's happening, when I move the mouse in both axis, only the first 2 bytes moves:
[mouse.txt](https://github.com/user-attachments/files/17005494/mouse.txt)

Slamy, 2024-09-15:
Oh no. I have a theory. This here catches my mind.
`HID device address = 1, instance = 1 is mounted
VID = 046d, PID = c52b
HID has 4 reports 2 2 1
Primary mouse`
It says 4 reports...
The report mode might be to blame. I have an idea to check...

I've added a branch for you:
https://github.com/Slamy/Yaumataca/compare/develop?expand=1

This does two things. It ditches the "report mode" in favor of the default boot compatibility mode. Wheels no longer work with this. But it behaves like a standard PS/2 mouse. Please try if this fixes the problem.
I assume this is related because no HID report descriptors are parsed yet with this project.
And maybe your mouse is a super special gamer mouse with multiple buttons and maybe multiple wheels.

andreacampanella, 2024-09-15:
it's a logitech mouse modle M310 with a unify receiver, I will try it

andreacampanella, 2024-09-15:
I'm building the branch and I get :
[ 98%] Building C object CMakeFiles/yaumataca.dir/pico-sdk/src/rp2_common/hardware_pio/pio.c.obj
/home/andrea/Yaumataca/src/handlers/hid_mouse.cpp: In member function 'virtual void MouseReportHandler::process_report(std::span<const unsigned char>)':
/home/andrea/Yaumataca/src/handlers/hid_mouse.cpp:26:22: error: unused variable 'i' [-Werror=unused-variable]
   26 |         for (uint8_t i : report) {
      |                      ^
compilation terminated due to -Wfatal-errors.
cc1plus: all warnings being treated as errors

Slamy, 2024-09-15:
Ah this is because you are building without CONFIG_DEBUG_PRINT. PRINTF is masked out. This print is rather helpful. It prints the full report for protocol analysis :-)

Slamy, 2024-09-15:
I've just experimented with a rapoo receiver. I'm having the same issues as you. But the workaround should fix your issues.

andreacampanella, 2024-09-15:
Yes, this is better:
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
Slamy, 2024-09-15:
Thank you for finding this. I'll recommend to remove the prints now as it will disrupt the usability because lag is generated. Afterwards please use the device with this change for now so you can actually use it with your beloved machine. We will leave this Issue open until a fix exists.
Right now I have another big project to tackle and I can't concentrate on multiple things in my free time.

andreacampanella, 2024-09-15:
ok, I tested it on my amiga but the mouse it's not moving, the mouse goes up and down but not left and right, it's this related to the debug?

Slamy, 2024-09-15:
Maybe this is still related to the pinout misunderstanding from the SVG.
```
        gpio_put(7, state.fire2); // Also used as Pot X
        gpio_put(9, state.fire1);
        gpio_put(15, state.up);
        gpio_put(11, state.fire3); // Also used as Pot Y
        gpio_put(14, state.down);
        gpio_put(12, state.left);
        gpio_put(10, state.right);
```
The SVG was wrong at some point. Those are the right numbers. According to the prints I see from you, those are exactly the values at the output of the Pico. Quadrature Encoding is indeed performed so it has to work. When up and down is fluent, this means that this is no longer related to Atari ST or C64 mode....
I hope you still have the report workaround inside.

andreacampanella, 2024-09-15:
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
How is this looking?

Slamy, 2024-09-15:
Ah you have a scope. That is very good. I mean, yes I see the signals. And if there is quadrature on the pins, there should be something occurring on the Amiga as long as you've soldered the right pins to the controller port. You can even now check the signals in the Amiga. It is no longer a software issue we are facing here. The quadrature on up down is the same as the one left right. Just different pins.

andreacampanella, 2024-09-15:
Ok, after some rewiring seems to be alright.

I do now have some problems with the left buttons.

The amiga seems to see the left button always pressed, like it's stuck, if I press it, it unstuck and it depressed until I pressed again, basically, it's sticky.

the middle button it's always high.

the right button doesn't work

Slamy, 2024-09-15:
Always pressed? This seems wrong.... Just in case. Do you have directly wired the Pico Pins to the Amiga? If yes, this is not the intended way as the Amiga is 5V while the Pico is officially not 5V tolerant. There are NPN transistors used as level shifters. This also means of course that the output of the Pico is inverted. A high signal on the Pico causes the transistor to pull down the signal on the Amiga which has an internal pull up.

andreacampanella, 2024-09-15:
No, of course not, I'm using two 8bit level translators (the one readily available on AliExpress and company) the rest of the mouse works well.

Slamy, 2024-09-15:
Yes, in this case you've build it differently than originally intended. I think you may just need to change the code in ```controller_port.hpp```. Every ```gpio_put``` has to be inverted.

Slamy, 2024-09-15:
I haven't tested this setup yet. Usually it is not expected to actually drive an Amiga controller port up. It has internal pull ups and pushing it down is sufficient for everything.... except the C64... or the Paddle inputs....

andreacampanella, 2024-09-15:
Cool, thank you very much for the project and the support :)

Slamy, 2024-11-30:
I know it has been a while. I've made some changes to the software. It is now capable of parsing the HID descriptor of a mouse. This should allow using your mouse together with a wheel.
Please check if the newest additions are fixing your issue.

andreacampanella, 2024-11-30:
I have completely forgotten about this, but tahst awesome ! I will give it a try !

Slamy, 2024-12-04:
Don't forget that you have build the device differently.^^
I recall you have used non inverting level shifters while I've used NPN transistors as inverting ones.

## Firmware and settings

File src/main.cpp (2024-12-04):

/**
 * @file main.cpp
 * @author André Zeps
 * @brief
 * @version 0.1
 * @date 2023-08-16
 *
 * @copyright Copyright (c) 2023
 *
 */

#include <stdio.h>
#include <stdlib.h>
#include <string.h>

#include "controller_port.hpp"
#include "global.hpp"
#include "hid_api.hpp"
#include "pico/stdlib.h"
#include "processors/mouse_c1351.hpp"
#include "processors/pipeline.hpp"
#include "tusb.h"
#include "utility.h"

//--------------------------------------------------------------------+
// MACRO CONSTANT TYPEDEF PROTYPES
//--------------------------------------------------------------------+

PIO C1351Converter::pio_{nullptr};
uint C1351Converter::offset_{0};

/**
 * @brief global instance of the primary input pipeline
 *
 * Usually this is considered bad practice, but the controller ports are also singleton here,
 * which means that the pipeline could exist for both as a single instance as well.
 *
 * Were are using std::optional here to control the time, the constructor is called as
 * it also initializes hardware and misconfiguration can occur when done to early.
 */
std::optional<Pipeline> gbl_pipeline;

/**
 * @brief First function to call
 *
 * Will never return.
 * @return int
 */
int main() {
    board_init();

    PRINTF("Yaumataca says hello!\n");

    // init host stack on configured roothub port
    tuh_init(BOARD_TUH_RHPORT);

    C1351Converter::load_calibration_data();
    C1351Converter::setup_pio();

    gbl_pipeline.emplace(LeftControllerPort::getInstance(), RightControllerPort::getInstance());

    for (;;) {
        // tinyusb host task
        tuh_task();
        hid_app_task();
        gbl_pipeline->run();

        static uint32_t button_debounce_cnt = 0;
        static uint32_t last_button_state = 0;
        bool button_state = board_button_read();

        if (!last_button_state && button_state && button_debounce_cnt == 0) {
            gbl_pipeline->cycle_mouse_mode();
            button_debounce_cnt = 100;
        } else if (button_debounce_cnt > 0 && !button_state) {
            button_debounce_cnt--;
        }
        last_button_state = button_state;
    }
}

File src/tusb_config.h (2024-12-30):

#pragma once

#ifdef __cplusplus
extern "C" {
#endif

//--------------------------------------------------------------------+
// Board Specific Configuration
//--------------------------------------------------------------------+

#if CFG_TUSB_MCU == OPT_MCU_RP2040
// change to 1 if using pico-pio-usb as host controller for raspberry rp2040
#define CFG_TUH_RPI_PIO_USB 0
#define BOARD_TUH_RHPORT CFG_TUH_RPI_PIO_USB
#endif

// RHPort number used for host can be defined by board.mk, default to port 0
#ifndef BOARD_TUH_RHPORT
#define BOARD_TUH_RHPORT 0
#endif

// RHPort max operational speed can defined by board.mk
#ifndef BOARD_TUH_MAX_SPEED
#define BOARD_TUH_MAX_SPEED OPT_MODE_DEFAULT_SPEED
#endif

//--------------------------------------------------------------------
// COMMON CONFIGURATION
//--------------------------------------------------------------------

// defined by compiler flags for flexibility
#ifndef CFG_TUSB_MCU
#error CFG_TUSB_MCU must be defined
#endif

#ifndef CFG_TUSB_OS
#define CFG_TUSB_OS OPT_OS_NONE
#endif

#ifndef CFG_TUSB_DEBUG
#define CFG_TUSB_DEBUG 1
#endif

// Enable Host stack
#define CFG_TUH_ENABLED 1

// Default is max speed that hardware controller could support with on-chip PHY
#define CFG_TUH_MAX_SPEED BOARD_TUH_MAX_SPEED

/* USB DMA on some MCUs can only access a specific SRAM region with restriction
 * on alignment. Tinyusb use follows macros to declare transferring memory so
 * that they can be put into those specific section. e.g
 * - CFG_TUSB_MEM SECTION : __attribute__ (( section(".usb_ram") ))
 * - CFG_TUSB_MEM_ALIGN   : __attribute__ ((aligned(4)))
 */
#ifndef CFG_TUH_MEM_SECTION
#define CFG_TUH_MEM_SECTION
#endif

#ifndef CFG_TUH_MEM_ALIGN
#define CFG_TUH_MEM_ALIGN __attribute__((aligned(4)))
#endif

//--------------------------------------------------------------------
// CONFIGURATION
//--------------------------------------------------------------------

// Size of buffer to hold descriptors and other data used for enumeration
#define CFG_TUH_ENUMERATION_BUFSIZE 1024

#define CFG_TUH_HUB 4
#define CFG_TUH_CDC 0
#define CFG_TUH_HID 4 // typical keyboard + mouse device can have 3-4 HID interfaces
#define CFG_TUH_MSC 0
#define CFG_TUH_VENDOR 0

// max device support (excluding hub device): 1 hub typically has 4 ports
#define CFG_TUH_DEVICE_MAX 10

// bare api support for xbox one controller and xbox 360 wireless receiver
#define CFG_TUH_API_EDPT_XFER 1

#define CFG_TUH_HID_EP_BUFSIZE 64

#ifdef __cplusplus
}
#endif

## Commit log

2023-08-14 Implemented most features
    C1351 emulation via PIO.
    Added basic unit test.
    Added first doxygen project config.
    Added auto fire handling.
    Added pipeline concept for the various components.
    Mouse mode switching via user button.
    Added controller port swapping.
    Added led blinking patterns.
    Added automatic switch between joystick and mouse.
    [yaumataca.kicad_pcb, yaumataca.kicad_sch]
2023-08-16 removed debugging prints
2023-08-18 Added Switch Pro Controller
    Implemented custom handshaking protocol
    Refined report reception for multiple classes
    Auto fire is also faster
2023-08-24 Unit tests Fixed unit tests
    [mouse_c1351.hpp]
2023-08-30 Documentation
    Just a little bit more text.
    Also updated schematics and created
    some diagrams.
    [yaumataca.kicad_pcb, yaumataca.kicad_sch]
2024-02-16 Add C1351 calibration mode
    Comes with small tool for c64
2024-02-21 First idea of a PCB
    All components on one side
    [yaumataca.kicad_pcb, yaumataca.kicad_sch]
2024-02-21 Added ordered PCB
    Components on both sides for an
    even smaller size.
    [yaumataca.kicad_pcb, yaumataca.kicad_sch]
2024-02-21 Added revision silkscreen
    It was missing from the order.
    No other change to the circuit
    [yaumataca.kicad_pcb]
2024-03-13 added first revision of housing
    [housing_v1-cap.stl, housing_v1-main.stl, housing_v1.FCStd]
2024-03-22 Fixed secondary fire on other port
    Also improved calibration method
    [mouse_c1351.hpp]
2024-03-22 Fixed muxing configuration timing
    [main.cpp]
2024-03-22 Use wheel instead of mouse during calibration
    more precision
2024-05-20 added second revision of housing
    improved mechanical stability
    button is now an actual button instead
    of just a hole
    fixed missing hole in PCB for the screw
    [housing_v2-Button.stl, housing_v2-Cap.stl, housing_v2-Main.stl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]
2024-05-22 Added reichelt order list
    [reichelt.csv]
2024-11-30 Fixed documentation
    The pinout diagram was not correct,
    after it was adapted for an easier PCB design.
2024-11-30 Added additional mouse swap mode
    Controller port swapping can now
    also be performed using 2 buttons instead of all 3.
    This should help with 2 button mice.
2024-11-30 Added support for a third fire button
2024-11-30 Additional Xbox controller VID PID combos
2024-11-30 Additional PS4 controller VID PID combos
2024-11-30 Additional PS3 controller VID PID combo
2024-11-30 Added HID Report Parser for Mice
    Fixes mice with more complex HID reports
    than the usual boot mode with one wheel byte
    at the end.
    [field_extractor.hpp]
2024-11-30 Documentation about adding devices
    A basic idea by Forum64 to get more people into the project
    Needs to be tested by a second person though
2024-12-01 Added Final Cart III hack
    The FC3 module muxes both controller
    ports to the POT lines of the SID.
    It is incompatible with two mice
    and the way, the Yaumataca simulates
    a C1351. This hack enforces to "let go"
    of these lines which indirectly might
    cause issues with C64 games that support
    additional fire buttons.
2024-12-01 Added C64 Micromys Wheel
    It uses the left and right direction signals
    Also added another release binary
    with Amiga wheel target being disabled.
2024-12-04 Change of boot up configuration
    Primary mouse port now starts as a mouse.
    Previously everything started as a joystick.
    Fixes Final Cart III after power cycle as the desktop
    mode is searching for a mouse.
    Also cleanup of debugging output
    [main.cpp]
2024-12-04 Resolve empty port after unplug
    With two joysticks and one mouse,
    it should be expected to separate
    the remaining devices after unplugging
    one.
2024-12-30 Fixed switching source reference
    during reattachment of input source.
    It has caused 2 input sources to share one
    primary switcher
2024-12-30 Added support for Xbox 360 Wireless Receiver
    Thanks to quadflyer8 for providing testing hardware
    Two Xbox 360 Wireless controllers are supported
    at the same time
